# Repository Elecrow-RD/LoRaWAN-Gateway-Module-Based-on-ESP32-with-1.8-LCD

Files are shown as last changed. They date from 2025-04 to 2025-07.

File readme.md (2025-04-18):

### 1, Product picture

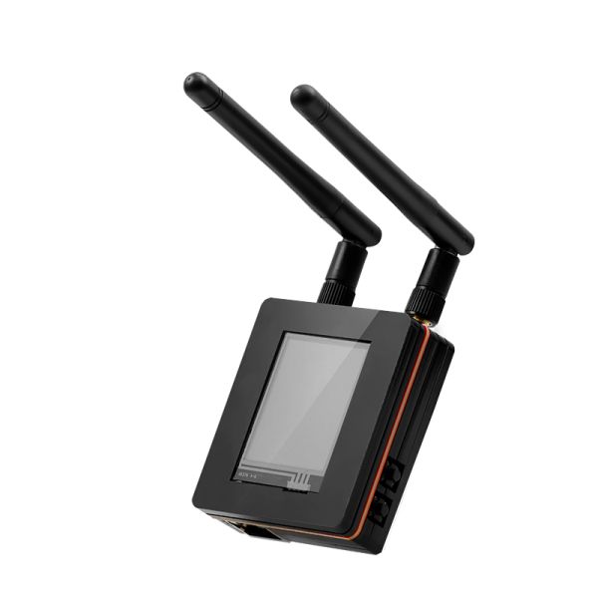
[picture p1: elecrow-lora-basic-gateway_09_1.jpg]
elecrow-lora-basic-gateway_09_1


### 2, Product version number

| | Hardware | Software | Remark |
| ---- | --- | --- | --- |
| 1 | V1.0 | V1.0 | latest |

### 3, product information

- | Main Processor Chip              | ESP32 WROOM32 with dual-core 32-bit LX6 microprocessor from Xtensa @ 240MHz |
  | -------------------------------- | ------------------------------------------------------------ |
  | LoRa RF transceiver module       | RA-01H                                                       |
  | RA-01H Supports frequency band   | 803MHZ-930MHZ                                                |
  | RA-01H Support modulation method | FSK、GFSK、MSK、LoRa                                         |
  | Channel                          | Single channel                                               |
  | Support Lorawan protocol         | Support Lorawan 1.0.3                                        |
  | WiFi Antenna                     | SMA 2.4G WiFi Antenna                                        |
  | Communication distance           | Obstructed state: up to 1 kmUnobstructed state: up to 1.8 kilometers |
  | Development environment          | Arduino/Micropython                                          |
  | Interface and function           | 1x USB-C interface,1x Ethernet Interface,1x Boot Button,1x Reset Button,2x Indicator Lights. |
  | Working input voltage            | USB DC-5V                                                    |
  | Operating Temperature            | -10°C ~ 65°C                                                 |
  | Dimensions                       | 65mm(L)x58mm(W)                                              |

### 4,Quick Start

##### Arduino IDE starts

1.Download the library files used by this product to the 'libraries' folder.

C:\Users\Documents\Arduino\libraries\



2.Open the Arduino IDE

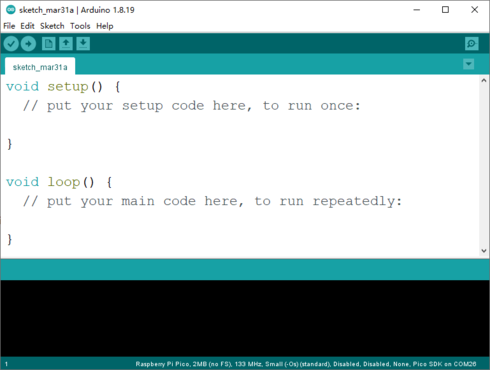
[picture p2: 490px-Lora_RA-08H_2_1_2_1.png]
490px-Lora_RA-08H_2_1_2_1


3.Open the code configuration environment and burn it

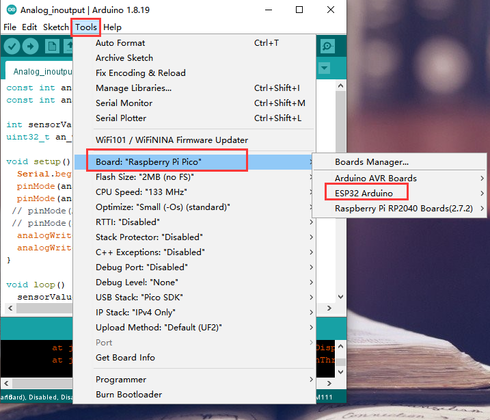
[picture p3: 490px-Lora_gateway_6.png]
490px-Lora_gateway_6


### 5,Folder structure.

|--Datasheet: Includes datasheets for components used in the project, providing detailed specifications, electrical characteristics, and pin configurations.

|--Eagle_SCH&PCB: Contains **Eagle CAD** schematic (`.sch`) and PCB layout (`.brd`) files. These are used for circuit design and PCB manufacturing.

|--example: Provides example code and projects to demonstrate how to use the hardware and libraries. These examples help users get started quickly.

|--factory_firmware: Stores pre-compiled factory firmware that can be directly flashed onto the device. This ensures the device runs the default functionality.

|--factory_sourcecode: Contains the source code for the factory firmware, allowing users to modify and rebuild the firmware as needed.

### 6,Pin definition

**IO port definition**

| GPIO0  | BOOT | GPIO1  | TXD0 | GPIO2  | RXD0 |
| --- | --- | --- | --- | --- | --- |
| GPIO3  | RXD0 | GPIO4  | LCD_DC | GPIO5  | DATA |
| GPIO6  | NC | GPIO7  | NC | GPIO8  | NC |
| GPIO9  | NC | GPIO10 | NC | GPIO11 | NC |
| GPIO12 | RA_RST | GPIO13 | RA_DIO1 | GPIO14 | RA_NSS |
| GPIO15 | XP_CS | GPIO16 | LCD_BLK | GPIO17 | RMII_CLK  |
| GPIO18 | ETH_MDIO | GPIO19 | RMII_TXD0 | GPIO20 | NC |
| GPIO21 | RMII_TX_EN  | GPIO22 | RMII_TXD1 | GPIO23 | ETH_MDC |
| GPIO24 | NC | GPIO25 | RMII_RXD0 | GPIO26 | RMII_RXD1 |
| GPIO27 | RMII_CRS_DV | GPIO28 | NC | GPIO29 | NC |
| GPIO30 | NC | GPIO31 | NC | GPIO32 | MOSI |
| GPIO33 | SCK | GPIO34 | RA_BUSY | GPIO35 | MISO |
| GPIO36 | NC | GPIO37 | NC | GPIO38 | C |
| GPIO39 | PEN | | | | |

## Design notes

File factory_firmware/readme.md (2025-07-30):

## The Wi-Fi connection password for Lora_Gateway_release_bin_v1.0 is 12345678.

## The Wi-Fi connection password for Lora_Gateway_release_bin_v2.0 is aaaabbbb.

## The firmware of zheg wifi-test can test whether your device's Wi-Fi is working properly. The Wi-Fi name is "ESP32 AP" and the password is "aaaabbbb". After connecting, check whether there is an IP address output on the serial port. If there is, it is working properly.

# How to install the factory demo firmware with flash download tool?

#### 1.Preparation:

- USB C cable
- Laptop/PC
- LoRaWAN Gateway Module Based on ESP32 with 1.8” LCD
- Flash download tool

Check whether the materials on the PCBA board are defective. Such as less material, false welding, tin and other bad phenomena.

#### 2.Flash the firmware 

##### Step1 LoRaWAN Gateway Module to the laptop/PC with USB-C cable. The power indicator will light up.

##### Step2 Open the flash download tool. 

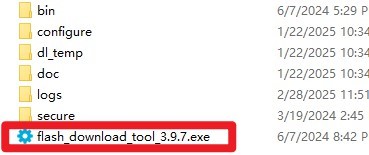
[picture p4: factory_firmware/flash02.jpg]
flash02


For the  Crowpanel Advance HMI ESP32 AI Display, the chip select ESP32:

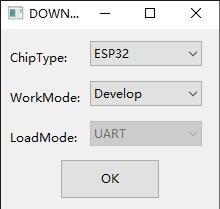
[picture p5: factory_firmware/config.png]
config


##### Step3

①Choose the firmware files;

②Enter the address: 

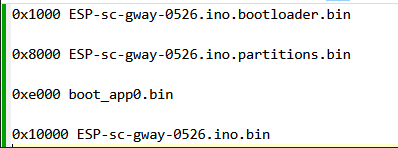
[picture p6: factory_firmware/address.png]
address


③Check the firmware files;

④Select the correct port number;

⑤Click “Start” to download

##### Step5 After the download is complete, blue FINISH will be displayed, and the progress bar at the bottom shows that it has come to an end.

download

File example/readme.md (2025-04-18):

**Arduino**: This folder contains sample programs for the Arduino platform, which is known for its ease of use and versatility in creating interactive electronic projects.

wiki:https://www.elecrow.com/wiki/lora-basic-gateway-module.html

# Library Descriptions

1. **Adafruit_BusIO**
   - A library for interfacing with various I/O devices on Adafruit platforms.

2. **Adafruit_seesaw_Library**
   - Provides support for the Adafruit Seesaw, a powerful I/O expander and controller.

3. **Adafruit_GFX-Library**
   - A graphics library that supports drawing text, images, and shapes on displays.

4. **Adafruit_ST7735-Library-master**
   - Specifically designed for ST7735-based displays, offering advanced graphical capabilities.

5. **aes**
   - Implements AES encryption and decryption algorithms for secure data handling.

6. **ArduinoJson**
   - Facilitates parsing and generating JSON data in Arduino projects.

7. **arduino.LoRa-master**
   - Supports communication using LoRa technology, ideal for long-range wireless applications.

8. **esp32-http-update**
   - Enables over-the-air updates for ESP32 devices via HTTP protocol.

9. **ESP8266_and_ESP32_Oled_Driver_for_SSD1306_display**
   - Drivers for OLED displays based on SSD1306 chips, compatible with both ESP8266 and ESP32.

10. **gBase64**
    - Encodes and decodes Base64 strings, useful for encoding binary data as ASCII characters.

11. **GUISlice-master**
    - A GUI library that simplifies creating user interfaces for embedded systems.

12. **LoRaCode**
    - Contains code snippets or examples related to LoRa communications.

13. **lv_demos-master**
    - Demonstration projects showcasing the use of LittlevGL (now LVGL), a lightweight graphics library.

14. **lvgl-master**
    - The core LittlevGL/LVGL library itself, providing rich graphical elements and widgets.

15. **Streaming**
    - Likely refers to streaming data or media; specifics would depend on implementation details not visible here.

16. **TFT_eSPI-master**
    - An optimized SPI interface driver for TFT displays, enhancing performance and functionality.

17. **TFT_Touch-master**
    - Adds touch screen capabilities to TFT displays, allowing interactive touch inputs.

18. **Time**
    - Manages time-related functions such as keeping track of system time, scheduling tasks, etc.

19. **TinyGPSPlus-1.0.2b**
    - Processes GPS data from NMEA sentences, extracting location information efficiently.

20. **WiFiManager-development**
    - Simplifies WiFi configuration by enabling users to connect to networks through a web portal.

21. **WiFiManager-master**
    - Similar to WiFiManager-development but might represent a stable release version.

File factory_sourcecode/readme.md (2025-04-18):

### 

## Key Functions in the Arduino Program

- # Function Descriptions

  ## `setup()`
  The `setup()` function is called once when the program starts. It initializes the serial communication, TFT display, touchscreen, and LVGL library. It also sets up the display driver, touchscreen driver, and initializes the UI.

  ## `loop()`
  The `loop()` function is called repeatedly and handles the main program logic. It checks for serial input to determine if the test program should run and handles the LVGL task handler to update the display.

  ## `my_disp_flush()`
  This function is a callback used by LVGL to flush the display buffer to the TFT display. It writes the pixel data to the display.

  ## `my_touchpad_read()`
  This function is a callback used by LVGL to read the touchscreen input. It retrieves the touch coordinates and updates the touch state.

  ## `touch_calibrate()`
  This function is used to calibrate the touchscreen. It prompts the user to touch specific corners of the screen and adjusts the calibration data accordingly.

  ## `label_xy()`
  This function creates label objects on the TOUCH screen to display the touch coordinates.

  ## `lv_example_bar()`
  This function creates a progress bar on the MENU screen and sets its initial value.

  ## `callback1()`
  This function is a callback used by the Ticker library to update the progress bar value and label text.

  ## `clearBufferArray()`
  This function clears the serial buffer array by setting all elements to NULL.

  ## `SD_test()`
  This function initializes the SD card and prints the directory structure to the serial monitor.

  ## `Ce_shi()`
  This function contains the test program logic. It listens for serial commands and performs various display tests such as showing colored screens, testing the touchscreen, and initializing the SD card.

  ## `lv_timer_handler()`
  This function is called to handle LVGL timer events, which are used to update the UI and handle animations.

  ## `watchdog_reboot()`
  This function reboots the system using the hardware watchdog timer.

  ## `pinMode()`
  This function sets the mode of a pin to either INPUT, OUTPUT, or INPUT_PULLUP.

  ## `digitalWrite()`
  This function writes a HIGH or LOW value to a digital pin.

  ## `analogWrite()`
  This function writes an analog value (PWM wave) to a pin.

  ## `delay()`
  This function pauses the program for the specified number of milliseconds.

  ## `Serial.begin()`
  This function initializes the serial communication with the specified baud rate.

  ## `Serial.read()`
  This function reads the next byte from the serial buffer.

  ## `Serial.println()`
  This function prints data to the serial port followed by a carriage return and newline.

  ## `tft.begin()`
  This function initializes the TFT display.

  ## `tft.setRotation()`
  This function sets the rotation of the TFT display.

  ## `tft.setTouch()`
  This function sets the touchscreen calibration data.

  ## `tft.fillScreen()`
  This function fills the entire TFT display with a specified color.

  ## `tft.getTouch()`
  This function retrieves the touch coordinates from the touchscreen.

  ## `lv_init()`
  This function initializes the LVGL library.

  ## `lv_disp_draw_buf_init()`
  This function initializes the display buffer used by LVGL.

  ## `lv_disp_drv_register()`
  This function registers the display driver with LVGL.

  ## `lv_indev_drv_register()`
  This function registers the input device driver with LVGL.

  ## `ui_init()`
  This function initializes the UI elements and screens.

  ## `lv_scr_load_anim()`
  This function loads a screen with an animation effect.

  ## `lv_obj_invalidate()`
  This function invalidates an object, causing it to be redrawn.

  ## `pinMode()`
  This function sets the mode of a pin to either INPUT, OUTPUT, or INPUT_PULLUP.

  ## `digitalWrite()`
  This function writes a HIGH or LOW value to a digital pin.

  ## `analogWrite()`
  This function writes an analog value (PWM wave) to a pin.

  ## `delay()`
  This function pauses the program for the specified number of milliseconds.

  ## `Serial.begin()`
  This function initializes the serial communication with the specified baud rate.

  ## `Serial.read()`
  This function reads the next byte from the serial buffer.

  ## `Serial.println()`
  This function prints data to the serial port followed by a carriage return and newline.

  ## `tft.begin()`
  This function initializes the TFT display.

  ## `tft.setRotation()`
  This function sets the rotation of the TFT display.

  ## `tft.setTouch()`
  This function sets the touchscreen calibration data.

  ## `tft.fillScreen()`
  This function fills the entire TFT display with a specified color.

  ## `tft.getTouch()`
  This function retrieves the touch coordinates from the touchscreen.

  ## `lv_init()`
  This function initializes the LVGL library.

  ## `lv_disp_draw_buf_init()`
  This function initializes the display buffer used by LVGL.

  ## `lv_disp_drv_register()`
  This function registers the display driver with LVGL.

  ## `lv_indev_drv_register()`
  This function registers the input device driver with LVGL.

  ## `ui_init()`
  This function initializes the UI elements and screens.

  ## `lv_scr_load_anim()`
  This function loads a screen with an animation effect.

  ## `lv_obj_invalidate()`
  This function invalidates an object, causing it to be redrawn.

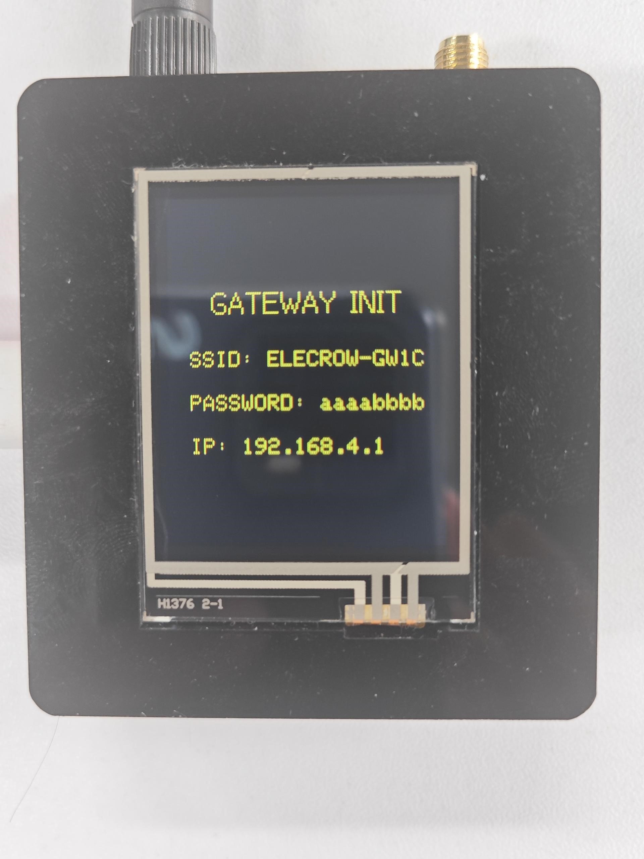
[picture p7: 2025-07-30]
factory_firmware/Lora_Gateway_release_bin_v2.0/password-aaaabbbbb.jpg

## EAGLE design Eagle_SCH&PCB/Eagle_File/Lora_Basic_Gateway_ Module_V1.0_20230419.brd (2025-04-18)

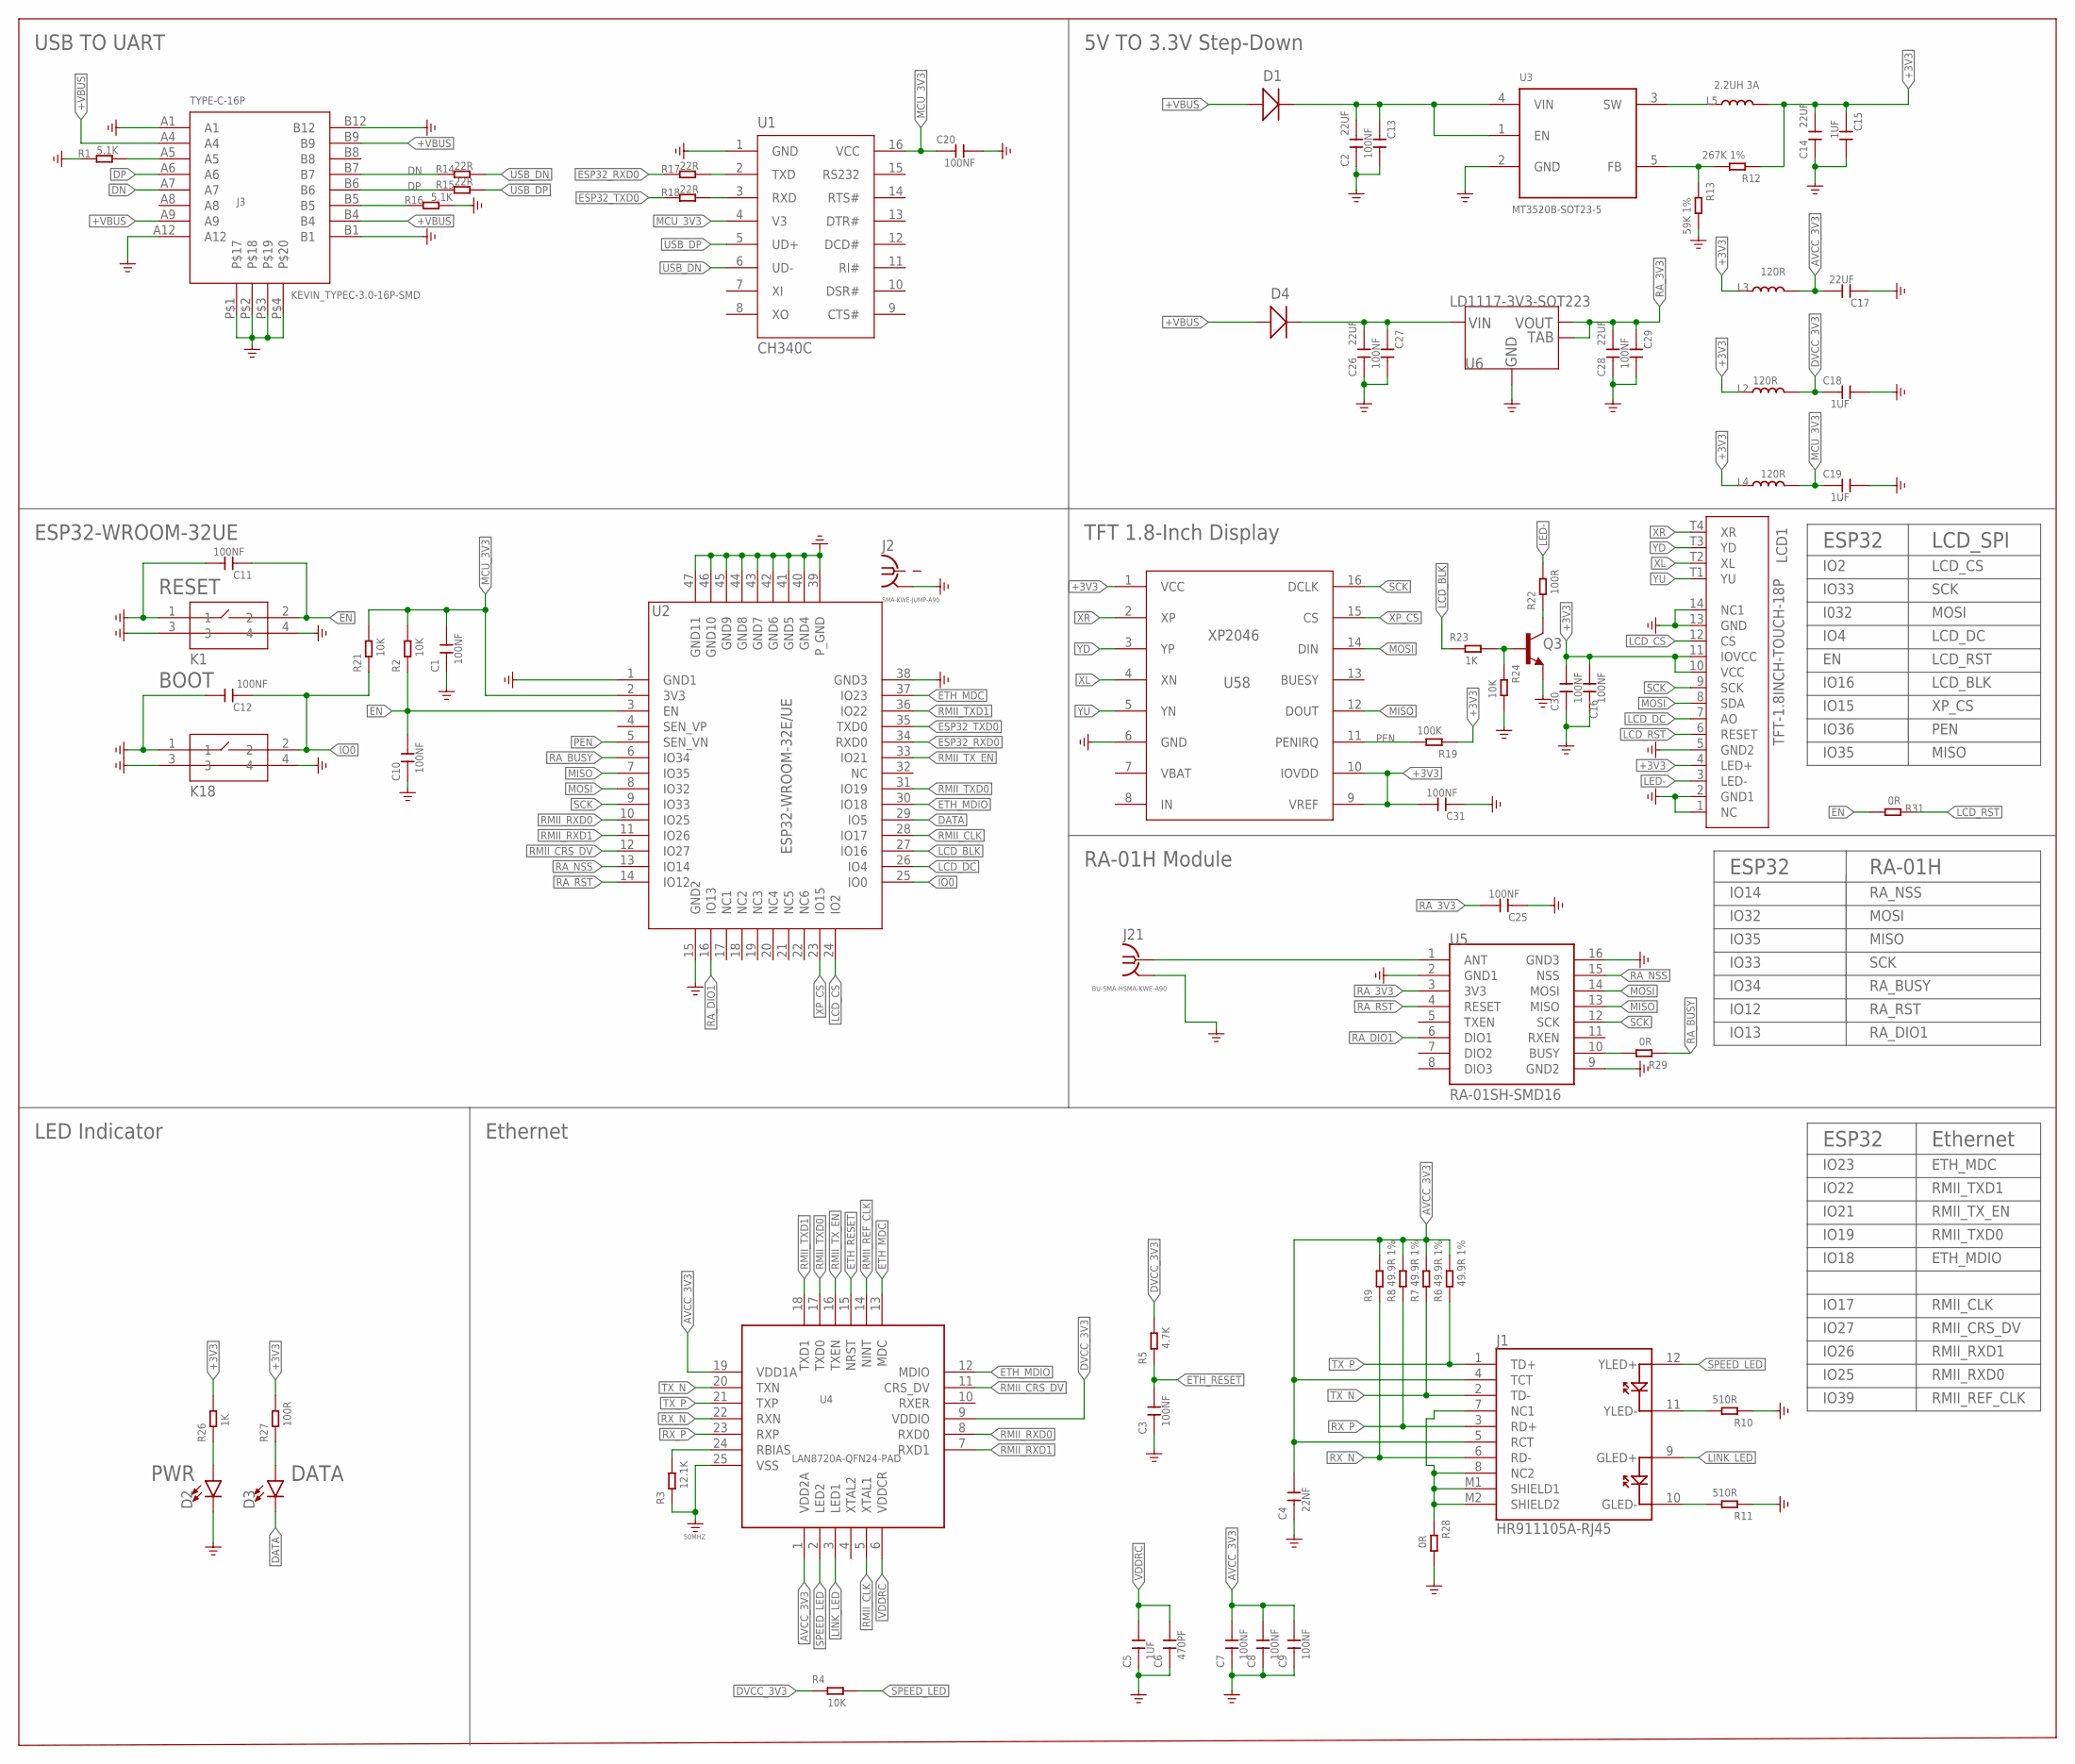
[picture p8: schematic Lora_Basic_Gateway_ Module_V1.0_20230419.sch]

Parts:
C1, C3, C7, C8, C9, C10, C11, C12, C13, C16, C20, C25, C27, C29, C30, C31: 100NF; C0603
C2, C14, C17, C26, C28: 22UF; C0805
C4: 22NF; C0603
C5, C15, C18, C19: 1UF; C0603
C6: 470PF; C0603
D1, D4: DIODEB130L-13-F; SMA
D2, D3: LED; LED-F3MM-DIP2-A90
J1: HR911105A-RJ45
J2: SMA-KWE-JUMP-A90
J3: KEVIN_TYPEC-3.0-16P-SMD; KEVIN_3.0TYPEC-SMD
J21: BU-SMA-HSMA-KWE-A90; SMA-KWE-A90
K1, K18: KEY_666MM_DIPA90; KEY_6*6*6MM_DIPA90
L2, L4: 120R; L0805
L3: 120R; L0603
L5: 2.2UH 3A; L0420
LCD1: TFT-1.8INCH-TOUCH-18P; TFT-1.8INCH-TOUCH-18P-SMD
Q3: 600mA/40V; SOT23-3
R1, R16: 5.1K; R0603
R2, R4, R21, R24: 10K; R0603
R3: 12.1K; R0603
R5: 4.7K; R0603
R6, R7, R8, R9: 49.9R 1%; R0603
R10, R11: 510R; R0603
R12: 267K 1%; R0603
R13: 59K 1%; R0603
R14, R15, R17, R18: 22R; R0603
R19: 100K; R0603
R22, R27: 100R; R0603
R23, R26: 1K; R0603
R28, R29, R31: 0R; R0603
U1: CH340C; SOP-16
U2: ESP32-WROOM-32E/UE; ESP32-WROOM-32UE
U3: MT3520B-SOT23-5; IC_SOT23-5
U4: LAN8720A-QFN24-PAD; QFN24-PAD
U5: RA-01SH-SMD16
U6: LD1117-3V3-SOT223; SOT223
U58: XP2046; XP2046-SSOP16

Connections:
+3V3: C14.2, C15.1, C16.2, C30.2, C31.2, L2.1, L3.1, L4.1, L5.2, LCD1.4 (LED+), LCD1.10 (VCC), LCD1.11 (IOVCC), R12.1, R19.1, R26.2, R27.2, U58.1 (VCC), U58.9 (VREF), U58.10 (IOVDD)
+VBUS: D1.2 (+), D4.2 (+), J3.A4, J3.A9, J3.B4, J3.B9
AVCC_3V3: C4.2, C7.2, C8.2, C9.2, C17.2, J1.4 (TCT), J1.5 (RCT), L3.2, R6.2, R7.2, R8.2, R9.2, U4.1 (VDD2A), U4.19 (VDD1A)
DATA: D3.K (C), U2.29 (IO5)
DN: J3.A7, J3.B7, R14.1
DP: J3.A6, J3.B6, R15.1
DVCC_3V3: C18.1, L2.2, R4.1, R5.2, U4.9 (VDDIO)
EN: C10.2, C11.1, K1.2, R2.1, R31.2, U2.3 (EN)
ESP32_RXD0: R17.1, U2.34 (RXD0)
ESP32_TXD0: R18.1, U2.35 (TXD0)
ETH_MDC: U2.37 (IO23), U4.13 (MDC)
ETH_MDIO: U2.30 (IO18), U4.12 (MDIO)
ETH_RESET: C3.2, R5.1, U4.15 (NRST)
GND: C1.1, C2.1, C3.1, C4.1, C5.1, C6.1, C7.1, C8.1, C9.1, C10.1, C11.2, C12.2, C13.2, C14.1, C15.2, C16.1, C17.1, C18.2, C19.2, C20.2, C25.1, C26.1, C27.2, C28.1, C29.2, C30.1, C31.1, D2.K (C), J2.2, J2.3, J2.4, J2.5, J3.A1, J3.A12, J3.B1, J3.B12, J3.P$1, J3.P$2, J3.P$3, J3.P$4, J21.2, J21.3 (2), J21.4 (2), J21.5 (2), K1.1, K1.3, K1.4, K18.1, K18.3, K18.4, LCD1.1 (NC), LCD1.2 (GND1), LCD1.5 (GND2), LCD1.13 (GND), LCD1.14 (NC1), Q3.2 (E), R1.1, R3.1, R10.1, R11.1, R13.2, R16.2, R24.2, R28.2, U1.1 (GND), U2.1 (GND1), U2.15 (GND2), U2.38 (GND3), U2.39 (P_GND), U2.40 (GND4), U2.41 (GND5), U2.42 (GND6), U2.43 (GND7), U2.44 (GND8), U2.45 (GND9), U2.46 (GND10), U2.47 (GND11), U3.2 (GND), U4.25 (VSS), U5.2 (GND1), U5.9 (GND2), U5.16 (GND3), U6.1 (GND), U58.6 (GND)
IO0: C12.1, K18.2, R21.1, U2.25 (IO0)
LCD_BLK: R23.1, U2.27 (IO16)
LCD_CS: LCD1.12 (CS), U2.24 (IO2)
LCD_DC: LCD1.7 (AO), U2.26 (IO4)
LCD_RST: LCD1.6 (RESET), R31.1
LED-: LCD1.3 (LED-), R22.2
LINK_LED: J1.9 (GLED+), U4.3 (LED1)
MCU_3V3: C1.2, C19.1, C20.1, L4.2, R2.2, R21.2, U1.4 (V3), U1.16 (VCC), U2.2 (3V3)
MISO: U2.7 (IO35), U5.13 (MISO), U58.12 (DOUT)
MOSI: LCD1.8 (SDA), U2.8 (IO32), U5.14 (MOSI), U58.14 (DIN)
unnamed: Q3.3 (C), R22.1
unnamed: D2.A, R26.1
unnamed: D3.A, R27.1
unnamed: C26.2, C27.1, D4.1 (-), U6.3 (VIN)
unnamed: R29.2, U5.10 (BUSY)
unnamed: J1.7 (NC1), J1.8 (NC2), J1.M1 (SHIELD1), J1.M2 (SHIELD2), R28.1
unnamed: Q3.1 (B), R23.2, R24.1
unnamed: J1.10 (GLED-), R11.2
unnamed: J21.1, U5.1 (ANT)
unnamed: J1.11 (YLED-), R10.2
unnamed: C2.2, C13.1, D1.1 (-), U3.1 (EN), U3.4 (VIN)
unnamed: R12.2, R13.1, U3.5 (FB)
unnamed: R3.2, U4.24 (RBIAS)
unnamed: L5.1, U3.3 (SW)
unnamed: J3.B5, R16.1
unnamed: J3.A5, R1.2
unnamed: R17.2, U1.2 (TXD)
unnamed: R18.2, U1.3 (RXD)
PEN: R19.2, U2.5 (SEN_VN), U58.11 (PENIRQ)
RA_3V3: C25.2, C28.2, C29.1, U5.3 (3V3), U6.2 (VOUT), U6.4 (TAB)
RA_BUSY: R29.1, U2.6 (IO34)
RA_DIO1: U2.16 (IO13), U5.6 (DIO1)
RA_NSS: U2.13 (IO14), U5.15 (NSS)
RA_RST: U2.14 (IO12), U5.4 (RESET)
RMII_CLK: U2.28 (IO17), U4.5 (XTAL1)
RMII_CRS_DV: U2.12 (IO27), U4.11 (CRS_DV)
RMII_REF_CLK: U4.14 (NINT)
RMII_RXD0: U2.10 (IO25), U4.8 (RXD0)
RMII_RXD1: U2.11 (IO26), U4.7 (RXD1)
RMII_TXD0: U2.31 (IO19), U4.17 (TXD0)
RMII_TXD1: U2.36 (IO22), U4.18 (TXD1)
RMII_TX_EN: U2.33 (IO21), U4.16 (TXEN)
RX_N: J1.6 (RD-), R9.1, U4.22 (RXN)
RX_P: J1.3 (RD+), R8.1, U4.23 (RXP)
SCK: LCD1.9 (SCK), U2.9 (IO33), U5.12 (SCK), U58.16 (DCLK)
SPEED_LED: J1.12 (YLED+), R4.2, U4.2 (LED2)
TX_N: J1.2 (TD-), R7.1, U4.20 (TXN)
TX_P: J1.1 (TD+), R6.1, U4.21 (TXP)
USB_DN: R14.2, U1.6 (UD-)
USB_DP: R15.2, U1.5 (UD+)
VDDRC: C5.2, C6.2, U4.6 (VDDCR)
XL: LCD1.T2 (XL), U58.4 (XN)
XP_CS: U2.23 (IO15), U58.15 (CS)
XR: LCD1.T4 (XR), U58.2 (XP)
YD: LCD1.T3 (YD), U58.3 (YP)
YU: LCD1.T1 (YU), U58.5 (YN)

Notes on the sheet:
ESP32
Ethernet
ETH_MDC
RMII_TXD1
RMII_TX_EN
RMII_TXD0
ETH_MDIO
RMII_CLK
RMII_CRS_DV
RMII_RXD1
RMII_RXD0
IO23
IO22
IO21
IO19
IO18
IO17
IO27
IO26
IO25
LCD_SPI
LCD_CS
SCK
MOSI
LCD_DC
LCD_RST
LCD_BLK
IO2
IO33
I032
IO4
IO16
RA-01H
RA_NSS
MISO
RA_BUSY
RA_RST
IO14
IO32
IO35

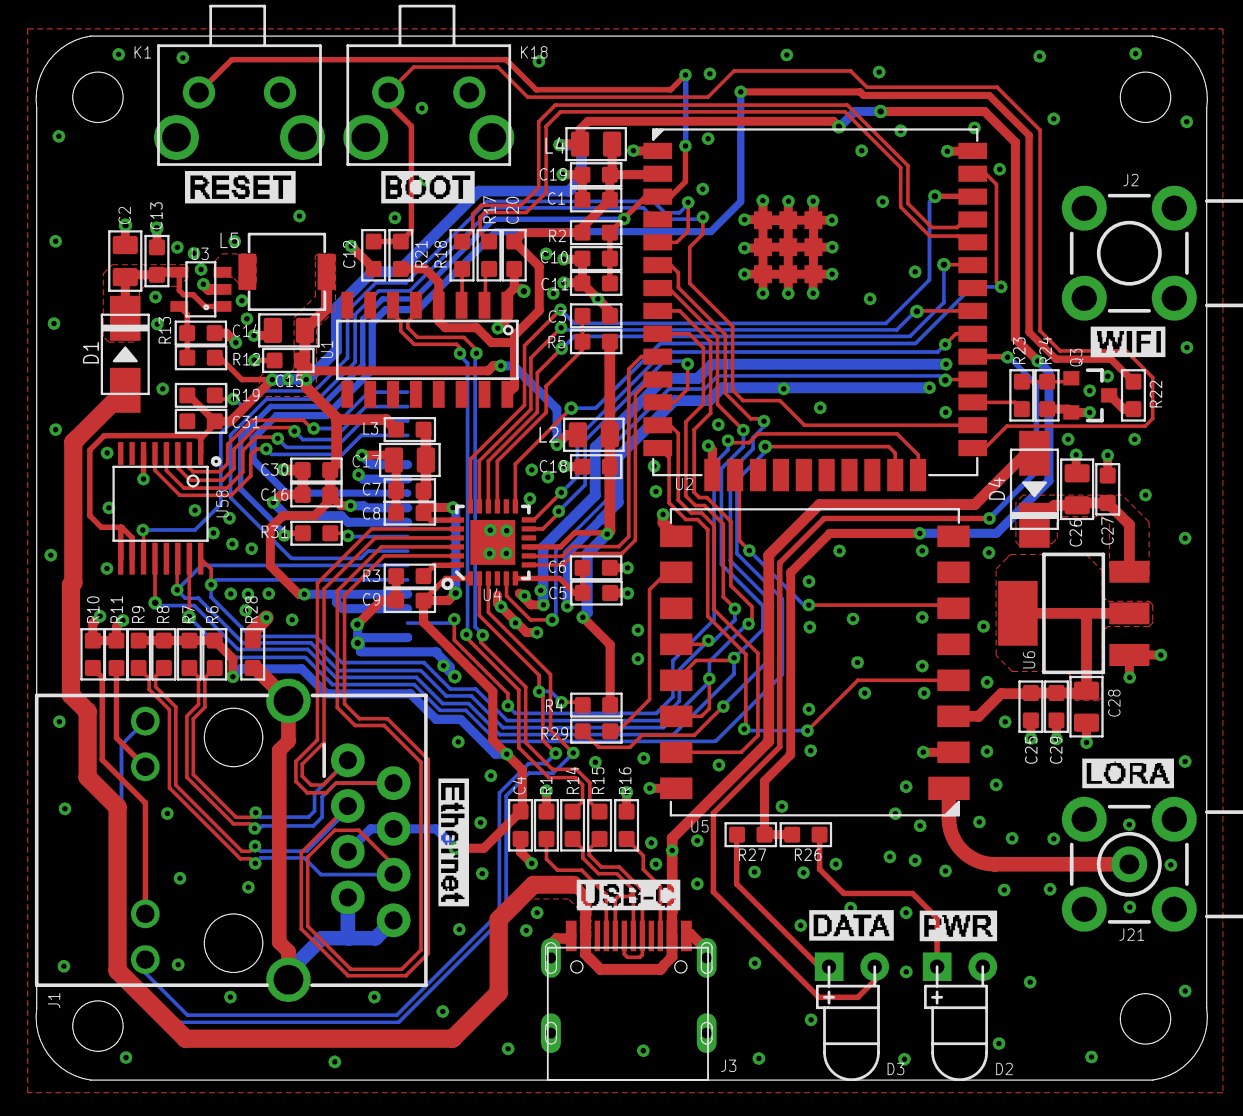
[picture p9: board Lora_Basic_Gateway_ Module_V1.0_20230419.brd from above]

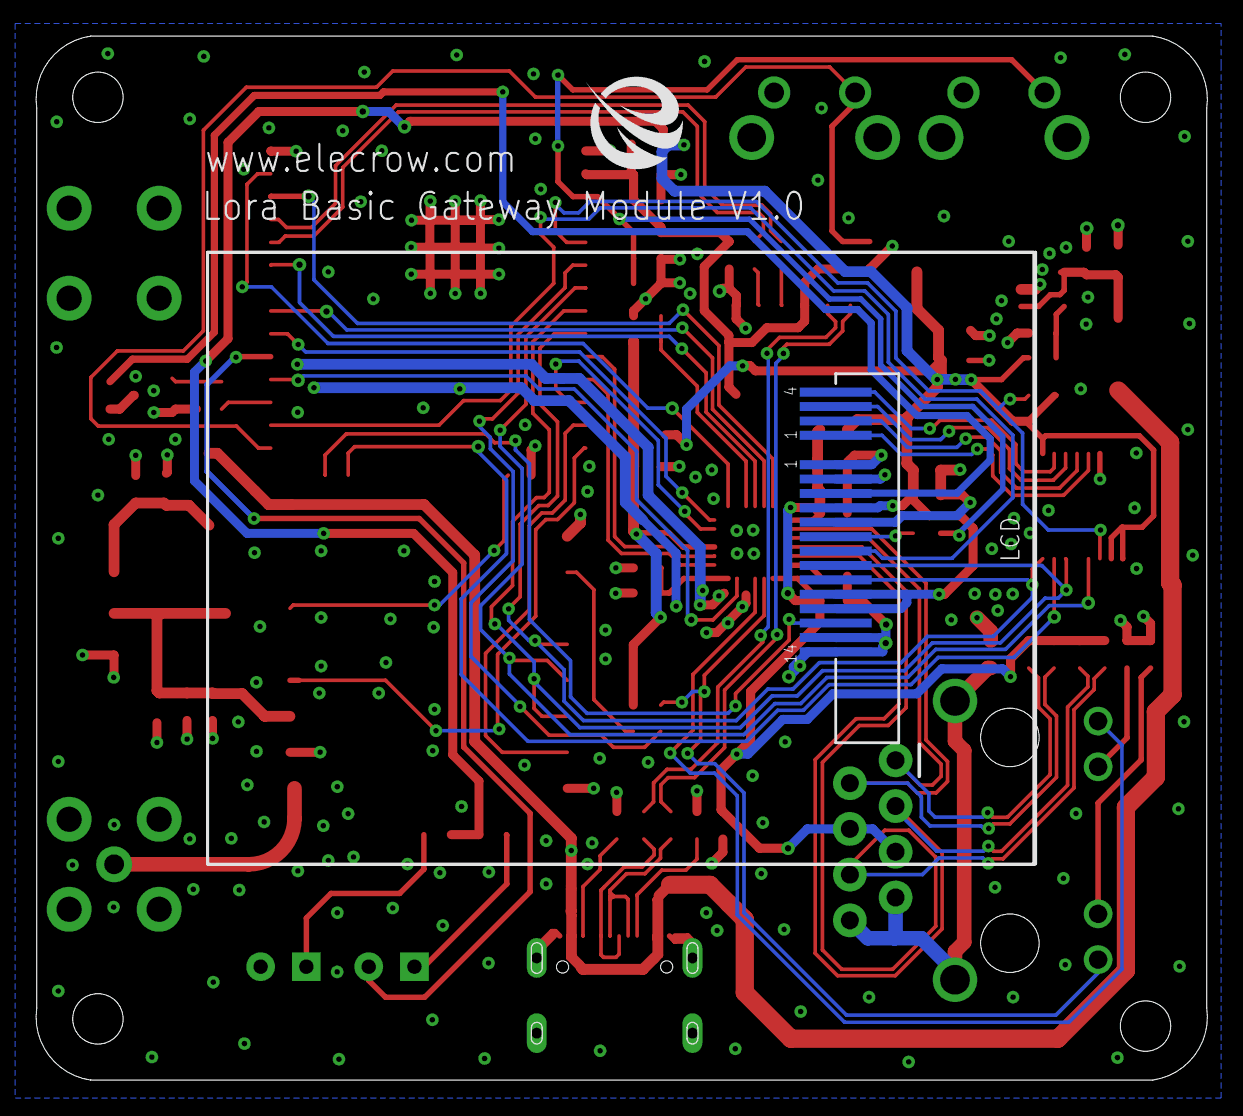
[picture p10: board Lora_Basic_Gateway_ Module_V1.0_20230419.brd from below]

Board: 2 copper layers, 65.1 x 58.0 mm, 79 parts (2 on the bottom side), 69 nets.

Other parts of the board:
U$160: ELECROW-NEW

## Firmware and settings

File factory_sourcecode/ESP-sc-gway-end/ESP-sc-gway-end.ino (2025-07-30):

// 1-channel LoRa Gateway for ESP8266 and ESP32     20230408
// Copyright (c) 2016-2020 free
//
// Based on work done by Thomas Telkamp for Raspberry PI 1-ch gateway and many others.
//
// All rights reserved. This program and the accompanying materials
// are made available under the terms of the MIT License
// which accompanies this distribution, and is available at
// https://opensource.org/licenses/mit-license.php
//
// NO WARRANTY OF ANY KIND IS PROVIDED
//
// The protocols and specifications used for this 1ch gateway:
// 1. LoRA Specification version V1.0 and V1.1 for Gateway-Node communication
//
// 2. Semtech Basic communication protocol between Lora gateway and server version 3.0.0
//	https://github.com/Lora-net/packet_forwarder/blob/master/PROTOCOL.TXT
//
// Notes:
// - Once call hostbyname() to get IP for services, after that only use IP
//	 addresses (too many gethost name makes the ESP unstable)
// - Only call yield() in main stream (not for background NTP sync).
//
// ----------------------------------------------------------------------------------------
#define ESP32_ARCH 1  //定义ESP32 SPI

#if defined (ARDUINO_ARCH_ESP32) || defined(ESP32)
#	define ESP32_ARCH 1
#	ifndef _PIN_OUT
#		define _PIN_OUT 4									// For ESP32 pin-out 4 is default
#	endif
#elif defined(ARDUINO_ARCH_ESP8266)
//
#else
#	error "Architecture unknown and not supported"
#endif


// The followion file contains most of the definitions
// used in other files. It should be the first file.
#include "configGway.h"										// contains the configuration data of GWay
#include "configNode.h"										// Contains the personal data of Wifi etc.

#include <Esp.h>											// ESP8266 specific IDE functions
#include <string.h>
#include <stdio.h>
#include <sys/types.h>
#include <unistd.h>
#include <fcntl.h>
#include <cstdlib>
//#include <time.h>
#include <sys/time.h>
#include <cstring>
#include <string>											// C++ specific string functions

#include <SPI.h>											// For the RFM95 bus
#include <TimeLib.h>										// http://playground.arduino.cc/code/time
#include <ArduinoJson.h>
#include <FS.h>												// ESP8266 Specific
#include <WiFiUdp.h>
#include <pins_arduino.h>
#include <gBase64.h>										// https://github.com/adamvr/arduino-base64 (changed the name)

// Local include files
#include "loraModem.h"
#include "loraFiles.h"
#include "oLED.h"

extern "C" {
#	include "lwip/err.h"
#	include "lwip/dns.h"
}

#if (_GATEWAYNODE==1) || (_LOCALSERVER==1)
#	include "AES-128_V10.h"
#endif

// ----------- Specific ESP32 stuff --------------
#if defined(ESP32_ARCH)
#	include <WiFi.h>
#	include <ESPmDNS.h>
#	include <SPIFFS.h>
#	include <WiFiManager.h>								// Standard lib for ESP WiFi config through an AP

#	define ESP_getChipId()   ((uint32_t)ESP.getEfuseMac())

//#	if _SERVER==1
//#		include <WebServer.h>								// Standard Webserver for ESP32
//#		include <Streaming.h>          						// http://arduiniana.org/libraries/streaming/
//WebServer server(_SERVERPORT);
//#	endif //_SERVER


#include <WiFi.h>
//#include <DNSServer.h>
#include <WebServer.h>
#include <Preferences.h>


// ----------- Specific ESP8266 stuff --------------
#elif defined(ARDUINO_ARCH_ESP8266)
extern "C" {
#		include "user_interface.h"
#		include "c_types.h"
}
#	include <ESP8266WiFi.h>									// Which is specific for ESP8266
#	include <ESP8266mDNS.h>
#	include <WiFiManager.h>									// Library for ESP WiFi config through an AP

#	define ESP_getChipId()   (ESP.getChipId())

#	if _SERVER==1
#		include <ESP8266WebServer.h>
#		include <Streaming.h>          						// http://arduiniana.org/libraries/streaming/
ESP8266WebServer server(_SERVERPORT);				// Standard IDE lib
#	endif //_SERVER

#	if _OTA==1
#		include <ESP8266httpUpdate.h>
#		include <ArduinoOTA.h>
#	endif //_OTA


#else
#	error "Architecture not supported"

#endif //ESP_ARCH

#include <DNSServer.h>										// Local DNSserver


// ----------- Declaration of variables --------------

bool led_show = false;
bool show_flag = true;
String Rx_last_time = "";
String Tx_last_time = "";
int Rx_cont = 0;
int Tx_cont = 0;
String sys_time = "";
uint8_t debug = 1;											// Debug level! 0 is no msgs, 1 normal, 2 extensive
uint8_t pdebug = P_MAIN ;									// Initially only MAIN and GUI

#if _GATEWAYNODE==1
#	if _GPS==1
#		include <TinyGPS++.h>
TinyGPSPlus gps;
HardwareSerial sGps(1);
#	endif //_GPS
#endif //_GATEWAYNODE

using namespace std;
byte 		currentMode = 0x81;
bool		sx1272 = true;									// Actually we use sx1276/RFM95

#define GATEWAY_REST_PIN 0
#define GATEWAY_RXTX_PIN 5
// ----------------------------------------------------------------------------
//
// Configure these values only if necessary!
//
// ----------------------------------------------------------------------------

// Set spreading factor (SF7 - SF12)
sf_t sf;							// Initial value of SF

// Set location, description and other configuration parameters
// Defined in ESP-sc_gway.h
//
float lat			= _LAT;									// Configuration specific info...
float lon			= _LON;
int   alt			= _ALT;
char platform[24]	= _PLATFORM; 							// platform definition
char email[40]		= _EMAIL;    							// used for contact email
char description[64] = _DESCRIPTION;							// used for free form description

// JSON definitions
StaticJsonDocument<312> jsonBuffer;							// Use of arduinoJson version 6!

// define servers

IPAddress ntpServer;										  // IP address of NTP_TIMESERVER
IPAddress ttnServer;										  // IP Address of thethingsnetwork server
IPAddress thingServer;										// Only if we use a second (backup) server

#include <ETH.h> //引用以使用ETH
#define ETH_PHY_ADDR    0
#define ETH_PHY_POWER  -1
#define ETH_PHY_MDC    23
#define ETH_PHY_MDIO   18
#define ETH_PHY_TYPE   ETH_PHY_LAN8720
#define ETH_CLK_MODE   ETH_CLOCK_GPIO17_OUT

WiFiUDP Udp;

time_t startTime = 0;										  // The time in seconds since 1970 that the server started.
uint32_t eventTime = 0;										// Timing of _event to change value (or not).
uint32_t sendTime = 0;										// Time that the last message transmitted
uint32_t doneTime = 0;										// Time to expire when CDDONE takes too long
uint32_t statTime = 0;										// last time we sent a stat message to server
uint32_t pullTime = 0;										// last time we sent a pull_data request to server
uint32_t rstTime  = 0;										// When to reset the timer
uint32_t fileTime = 0;										// Write the configuration to file

#define TX_BUFF_SIZE  1024								// Upstream buffer to send to MQTT
#define RX_BUFF_SIZE  1024								// Downstream received from MQTT
#define STATUS_SIZE	  512									// Should(!) be enough based on the static text .. was 1024

#if _SERVER==1
uint32_t wwwtime = 0;
#endif
#if NTP_INTR==0
uint32_t ntptimer = 0;
#endif
#if _GATEWAYNODE==1
uint16_t frameCount = 0;									// We write this to SPIFF file
#endif
#ifdef _PROFILER
uint32_t endTmst = 0;
#endif

// Init the indexes of the data we display on the webpage
// We use this for circular buffers
uint16_t iMoni = 0;
uint16_t iSeen = 0;
uint16_t iSens = 0;

// volatile bool inSPI This initial value of mutex is to be free,
// which means that its value is 1 (!)
//
int16_t mutexSPI = 1;

// ----------------------------------------------------------------------------
// FORWARD DECLARATIONS
// These forward declarations are done since other .ino fils are linked by the
// compiler/linker AFTER the main ESP-sc-gway.ino file.
// And espcecially when calling functions with ICACHE_RAM_ATTR the complier
// does not want this.
// Solution can also be to specify less STRICT compile options in Makefile
// ----------------------------------------------------------------------------

void ICACHE_RAM_ATTR Interrupt_0();
void ICACHE_RAM_ATTR Interrupt_1();

int sendPacket(uint8_t *buf, uint8_t length);							// _txRx.ino forward

void printIP(IPAddress ipa, const char sep, String & response);			// _wwwServer.ino
void setupWWW();														// _wwwServer.ino forward

void mPrint(String txt);												// _utils.ino
int getNtpTime(time_t *t);												// _utils.ino
int mStat(uint8_t intr, String & response);								// _utils.ino
void SerialStat(uint8_t intr);											// _utils.ino
void printHexDigit(uint8_t digit, String & response);					// _utils.ino
int inDecodes(char * id);												// _utils.ino
static void stringTime(time_t t, String & response);					// _utils.ino

int initMonitor(struct moniLine *monitor);								// _loraFiles.ino
void initConfig(struct espGwayConfig *c);								// _loraFiles.ino
int writeSeen(const char *fn, struct nodeSeen *listSeen);				// _loraFiles.ino
int readGwayCfg(const char *fn, struct espGwayConfig *c);				// _loraFiles.ino

void setupOta(char *hostname);											// _otaServer.ino

void initLoraModem();													// _loraModem.ino
void rxLoraModem();														// _loraModem.ino
void writeRegister(uint8_t addr, uint8_t value);						// _loraModem.ino
void cadScanner();														// _loraModem.ino
void startReceiver();													// _loraModem.ino

void stateMachine();													// _stateMachine.ino

bool connectUdp();														// _udpSemtech.ino
int readUdp(int packetSize);											// _udpSemtech.ino
int sendUdp(IPAddress server, int port, uint8_t *msg, uint16_t length);		// _udpSemtech.ino
void sendstat();														// _udpSemtech.ino
void pullData();														// _udpSemtech.ino

#if _MUTEX==1
void ICACHE_FLASH_ATTR CreateMutux(int *mutex);
bool ICACHE_FLASH_ATTR GetMutex(int *mutex);
void ICACHE_FLASH_ATTR ReleaseMutex(int *mutex);
#endif


void init_ST7735();
void ST7735_Clear();
void ST7735_SHOW_TEST(int x, int y, int w, int h, int text_x, int text_y, String str, int str_font, int str_size);   //显示字符
void ROLL_Text(int x, int y, int w, int h, int text_x, int text_y, String str, int str_font, int str_size);
bool ST7735_GET_TOUCH();

Preferences prefs;
const char* AP_NAME = "ELECROW-GW1C";//Web配网模式下的AP-wifi名字
const char* AP_PASSWORD = "aaaabbbb";//Web配网模式下的AP-wifi密码

//暂时存储Gateway配置信息
char sta_gatewayMode[32] = {0};
char sta_ssid[64] = {0};
char sta_password[64] = {0};
char sta_gatewayid[64] = {0};
char sta_serverAddr[64] = {0};
char sta_serverPort[64] = {0};
char sta_region[32] = {0};
char sta_getway_channel[32] = {0};
char sta_getway_sf[32] = {0};
char sta_getway_utc[32] = {0};
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
void loop ()
{

  int cont_rest = 0;
  // 检测按键是否按下，当按键按下时将返回低电平
  if (digitalRead(GATEWAY_REST_PIN) == LOW) {
    delay(50);
    // 按键按下 计时
    while(digitalRead(GATEWAY_REST_PIN) == LOW)
    {
      delay(100);
      cont_rest++;
      Serial.println("rest cont = " + String(cont_rest));
      if(cont_rest == 30)
      {        
        prefs.begin("gatewayConfig",false);//为false才能删除键值
        Serial.println(prefs.freeEntries());//查询清除前的剩余空间
        
        prefs.remove("netMode"); 
        prefs.remove("wifiid"); 
        prefs.remove("wifipass"); 
        prefs.remove("gatewayid"); 
        prefs.remove("serverAddr"); 
        prefs.remove("serverPort"); 
        prefs.remove("region"); 
        prefs.remove("getway_channel"); 
        prefs.remove("getway_sf"); 
        prefs.clear();

        ST7735_Clear();
        delay(500);
        Serial.println(prefs.freeEntries());//查询清除后的剩余空间
        prefs.end();
    
        Serial.println("remove config --> ESP32 restart ");
        ESP.restart(); //重启ESP32
      }
    }
    
  } 

  int packetSize;
  uint32_t nowSeconds = now();

  gateway_server.handleClient();

   if(mode_getwag == "wifi" || mode_getwag == "net") 
  {

      ST7735_GET_TOUCH();
    
      // So if we are connected
      // Receive UDP PUSH_ACK messages from server. (*2, par. 3.3)
      // This is important since the TTN broker will return confirmation
      // messages on UDP for every message sent by the gateway. So we have to consume them.
      // As we do not know when the server will respond, we test in every loop.
      while ( (packetSize = Udp.parsePacket()) > 0) {
    #		if _MONITOR>=1
        if ((debug >= 3) && (pdebug & P_TX)) {
          mPrint("loop:: readUdp available");
        }
    #		endif //_MONITOR
    
        // DOWNSTREAM
        // Packet may be PKT_PUSH_ACK (0x01), PKT_PULL_ACK (0x03) or PKT_PULL_RESP (0x04)
        // This command is found in byte 4 (buffer[3])
    
        if (readUdp(packetSize) < 0) {
    #			if _MONITOR>=1
          if (debug >= 0)
            mPrint("Dwn readUdp ERROR, returning < 0");
    #			endif //_MONITOR
          break;
        }
        // Now we know we succesfully received message from host
        // If return value is 0, we received a NTP message,
        // otherwise a UDP message with other TTN content, all ACKs are 4 bytes long
        else {
          //_event=1;									// Could be done double if more messages received
          //mPrint("Dwn udp received="+String(micros())+", packetSize="+String(packetSize));
        }
      }
    
      yield();
    
      // check for event value, which means that an interrupt has arrived.
      // In this case we handle the interrupt ( e.g. message received)
      // in userspace in loop().
      //
      stateMachine();											// do the state machine
    
      // After a quiet period, make sure we reinit the modem and state machine.
      // The interval is in seconds (about 15 seconds) as this re-init
      // is a heavy operation.
      // So it will kick in if there are not many messages for the gateway.
      // Note: Be careful that it does not happen too often in normal operation.
      //
      if ( ((nowSeconds - statr[0].time) > _MSG_INTERVAL) &&
           (msgTime <= statr[0].time) )
      {
    #		if _MONITOR>=1
        if ((debug >= 2) && (pdebug & P_MAIN)) {
          String response = "";
          response += "REINIT:: ";
          response += String( _MSG_INTERVAL );
          response += (" ");
          mStat(0, response);
          mPrint(response);
        }
    #		endif //_MONITOR
    
        yield();											// Allow buffer operations to finish
    
        if ((gwayConfig.cad) || (gwayConfig.hop)) {
          _state = S_SCAN;
          sf = SF7;
          cadScanner();
        }
        else {
          _state = S_RX;
          rxLoraModem();
        }
        writeRegister(REG_IRQ_FLAGS_MASK, (uint8_t) 0x00);
        writeRegister(REG_IRQ_FLAGS, (uint8_t) 0xFF);		// Reset all interrupt flags
        msgTime = nowSeconds;
      }
    
      // If event is set, we know that we have a (soft) interrupt.
      // After all necessary web/OTA services are scanned, we will
      // reloop here for timing purposes.
      // Do as less yield() as possible.
      if (_event == 1) {
        return;
      }
      else yield();
       
      // stat PUSH_DATA message (*2, par. 4)
      //
      if ((nowSeconds - statTime) >= _STAT_INTERVAL) {		// Wake up every xx seconds
        yield();											// on 26/12/2017
        sendstat();											// Show the status message and send to server
    #		if _MONITOR>=1
        if ((debug >= 2) && (pdebug & P_MAIN)) {
          mPrint("Send Pushdata sendstat");
        }
    #		endif //_MONITOR
    
        // If the gateway behaves like a node, we do from time to time
        // send a node message to the backend server.
        // The Gateway node message has nothing to do with the STAT_INTERVAL
        // message but we schedule it in the same frequency.
        //
    #		if _GATEWAYNODE==1
        if (gwayConfig.isNode) {
          // Give way to internal some Admin if necessary
          yield();
    
          // If the 1ch gateway is a sensor itself, send the sensor values
          // could be battery but also other status info or sensor info
    
          if (sensorPacket() < 0) {
    #				if _MONITOR>=1
            if ((debug >= 1) || (pdebug & P_MAIN)) {
              mPrint("sensorPacket: Error");
            }
    #				endif //_MONITOR
          }
        }
    #		endif//_GATEWAYNODE
        statTime = nowSeconds;
      }
    
    
      // send PULL_DATA message (*2, par. 4)
      //
      // This message will also restart the server which taken approx. 3 ms.
      nowSeconds = now();
      if ((nowSeconds - pullTime) >= _PULL_INTERVAL) {		// Wake up every xx seconds
    
        yield();
        pullData();											// Send PULL_DATA message to server
        //startReceiver();
        pullTime = nowSeconds;
    
    #		if _MONITOR>=1
        if ((debug >= 2) && (pdebug & P_RX)) {
          String response = "UP ESP-sc-gway:: PKT_PULL_DATA message sent: micr=";
          printInt(micros(), response);
          mPrint(response);
        }
    #		endif //_MONITOR
      }
    
    
      // send RESET_DATA message (*2, par. 4)
      //
      // This message will also restart the server which taken approx. 3 ms.
      nowSeconds = now();
      if ((nowSeconds - rstTime) >= _RST_INTERVAL) {			// Wake up every xx seconds
    
        yield();
        startReceiver();
        rstTime = nowSeconds;
    
    #		if _MONITOR>=1
        if ((debug >= 2) && (pdebug & P_MAIN)) {
          String response = "UP ESP-sc-gway:: RST_DATA message sent: micr=";
          printInt(micros(), response);
          mPrint(response);
        }
    #		endif //_MONITOR
      }
    
    
      // If we do our own NTP handling (advisable)
      // We do not use the timer interrupt but use the timing
      // of the loop() itself which is better for SPI
//    #	if NTP_INTR==0
//      // Set the time in a manual way. Do not use setSyncProvider
//      //  as this function may collide with SPI and other interrupts
//      // Note: It can be that we do not receive a time this loop (no worries)
//      yield();
//      if (nowSeconds - ntptimer >= _NTP_INTERVAL) {
//        yield();
//        time_t newTime;
//        if (getNtpTime(&newTime) <= 0) {
//    #				if _MONITOR>=1
//          if (debug >= 2) {
//            mPrint("loop:: WARNING Time not set (yet). Time=" + String(newTime) );
//          }
//    #				endif //_MONITOR
//        }
//        else {
//          setTime(newTime);
//          if (year(now()) != 1970) {						// Do not when year(now())=="1970"
//            ntptimer = nowSeconds;						// beacause of "FORMAT"
//          }
//        }
//      }
//    #	endif//NTP_INTR
    
//    #	if _MAXSEEN>=1
//      if ((nowSeconds - fileTime) >= _FILE_INTERVAL) {
//        writeSeen(_SEENFILE, listSeen);
//        fileTime = nowSeconds;
//      }
//    #	endif //_MAXSEEN
    
  }
  else
  {
     #if _MONITOR>=1
        Serial.println("Config Network ....");
        delay(1000);
    #endif //_MONITOR
  }

}//loop

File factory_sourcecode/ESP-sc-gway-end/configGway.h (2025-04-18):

// 1-channel LoRa Gateway for ESP32 and ESP8266
// Copyright (c) 2016-2020 

#define VERSION "V.6.2.5.EU868"

//
// Based on work done by Thomas Telkamp for Raspberry PI 1ch gateway and many others.
//
// All rights reserved. This program and the accompanying materials
// are made available under the terms of the MIT License
// which accompanies this distribution, and is available at
// https://opensource.org/licenses/mit-license.php
//
// NO WARRANTY OF ANY KIND IS PROVIDED
//
// This file contains a number of compile-time settings that can be set on (=1) or off (=0)
// The disadvantage of compile time is minor compared to the memory gain of not having
// too much code compiled and loaded on your ESP device.
//
// NOTE: 
// If version is for ESP32 Heltec board, compile with ESP32 setting and board 
// "ESP32 Dev Module" or "Heltec WiFi Lora 32"
// 
// For ESP8266 Wemos: compile with "Wemos R1 D1" and choose
// the right _PIN_OUT below. Selecting Oled while that is not connected does not 
// really matter (so you can leave that in).
//
// The source has been optimized for PlatformIO usage. That means some variables
// can be defined in the .platformio.ini file. Please look at the example file to see 
// how to set these #defines
//
// ========================================================================================


// Define whether we should do a formatting of SPIFFS when starting the gateway
// This is usually a good idea if the webserver is interrupted halfway a writing
// operation. Also to be used when software is upgraded
// Normally, value 0 is a good default and should not be changed.
#if !defined _SPIFFS_FORMAT
#	define _SPIFFS_FORMAT 0
#endif


// Allows configuration through WifiManager AP setup. Must be 0 or 1	
#if !defined _WIFIMANAGER				
#	define _WIFIMANAGER 0
#endif


// Debug message will be put on Serial is this one is set.
// If set to 0, no printing to USB devices is done.
// Set to 1 it will print all user level messages (with correct debug set)
// If set to 2 it will also print interrupt messages (not recommended)
#if !defined _DUSB
#	define _DUSB 1
#endif


// Define the monitor screen. When it is greater than 0 then logging is displayed in
// the special screen at the GUI.
// If _DUSB is also set to 1 then most messages will also be copied to USB devices.
#if !defined _MONITOR
#	define _MONITOR 1
#endif


// Gather statistics on sensor and Wifi status
// 0= No statistics
// 1= Keep track of messages statistics, number determined by _MAXSTAT
// 2= Option 1 + Keep track of messages received PER each SF (default)
// 3= See Option 2, but with extra channel info (Not used when Hopping is not selected)
#if !defined _STATISTICS
#	define _STATISTICS 3
#endif

// Define the frequency band the gateway will listen on. Valid options are
// EU863_870	Europe 
// US902_928	North America
// AU925_928	Australia
// CN470_510	China
// IN865_867	India
// CN779-787	(Not Used!)
// EU433		Europe
// AS923		(Not Used)
// You can find the definitions in "loraModem.h" and frequencies in
// See https://www.thethingsnetwork.org/docs/lorawan/frequency-plans.html
//#define EU863_870 1
 

// Define the CLASS mode of the gateway
// A: Baseline Class
// B: Beacon/Battery Class
// C: Continuous Listen Class
#define _CLASS "A"


// Define whether to use the old Semtech gateway API, which is still supported by TTN,
// but is more lightweight than the new TTN tcp based protocol.
// NOTE: Only one of the two should be defined! TTN Router project has stopped
//
#define _UDPROUTER 1
//#define _TTNROUTER 1


// The spreading factor is the most important parameter to set for a single channel
// gateway. It specifies the speed/datarate in which the gateway and node communicate.
// As the name says, in principle the single channel gateway listens to one channel/frequency
// and to one spreading factor only.
// This parameters contains the default value of SF, the actual version can be set with
// the webserver and it will be stored in SPIFF
// NOTE: The frequency is set in the loraModem.h file and is default 868.100000 MHz.
//#define _SPREADING SF7


// Channel Activity Detection
// This function will scan for valid LoRa headers and determine the Spreading 
// factor accordingly. If set to 1 we will use this function which means the 
// 1-channel gateway will become even more versatile. If set to 0 we will use the
// continuous listen mode.
// Using this function means that we HAVE to use more dio pins on the RFM95/sx1276
// device and also connect enable dio1 to detect this state. 
#define _CAD 0


// CRCCHECK
// Defines whether we should check on the CRC of RXDONE messages (see stateMachine.ino)
// This should prevent us from getting a lot os stranges messgages of unknown nodes.
// Note: DIO3 must be connected for this to work (Heltec and later Wemos gateways). 
#define _CRCCHECK 1
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

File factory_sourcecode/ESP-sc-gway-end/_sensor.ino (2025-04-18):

// sensor.ino; 1-channel LoRa Gateway for ESP8266 and ESP32
// Copyright (c) 2016-2020 
//
// All rights reserved. This program and the accompanying materials
// are made available under the terms of the MIT License
// which accompanies this distribution, and is available at
// https://opensource.org/licenses/mit-license.php
//
// NO WARRANTY OF ANY KIND IS PROVIDED
//
// This file contains code for using the single channel gateway also as a sensor node. 
// Please specify the DevAddr and the AppSKey below (and on your LoRa backend).
// Also you will have to choose what sensors to forward to your application.
//
// Note: disable sensors not used in configGway.h
//	- The GPS is included on TTGO T-Beam ESP32 boards by default.
//	- The battery sensor works by connecting the VCC pin to A0 analog port
// ============================================================================
	
#if _GATEWAYNODE==1

#include "LoRaCode.h"

unsigned char DevAddr[4]  = _DEVADDR ;				// see configGway.h


// Only used by GPS sensor code
#if _GPS==1
// ----------------------------------------------------------------------------
// Smartdelay is a function to delay processing but in the loop get info 
// from the GPS device
// ----------------------------------------------------------------------------
void smartDelay(uint32_t ms)                
{
	uint32_t start = millis();
	do
	{
		while (sGps.available()) {
			gps.encode(sGps.read());
		}
		yield();									// MMM Maybe  enable to fill buffer
	} while (millis() - start < ms);
}
#endif //_GPS





// ----------------------------------------------------------------------------
// LoRaSensors() is a function that puts sensor values in the MACPayload and 
// sends these values up to the server. For the server it is impossible to know 
// whther or not the message comes from a LoRa node or from the gateway.
//
// The example code below adds a battery value in lCode (encoding protocol) but
// of-course you can add any byte string you wish
//
// Parameters: 
//	- buf: contains the buffer to put the sensor values in (max==xx);
// Returns:
//	- The amount of sensor characters put in the buffer
//
// NOTE: The code in LoRaSensors() is provided as an example only.
//	The amount of sensor values as well as their message layout may differ
//	for each implementation.
//	Also, the message format used by this gateway is LoraCode, a message format
//	developed by me for sensor values. Each value is uniquely coded with an
//	id and a value, and the total message contains its length (less than 64 bytes)
//	and a parity value in byte[0] bit 7.
// ----------------------------------------------------------------------------
int LoRaSensors(uint8_t *buf) {

#	if defined(_LCODE)
#		if defined(_RAW) 
#		error "Only define ONE encoding in configNode.h, _LOCDE or _RAW"
#		endif

		String response="";
		uint8_t tchars = 1;
		buf[0] = 0x86;								// 134; User code <lCode + len==3 + Parity
		
#		if _MONITOR>=1
		if ((debug>=1) && (pdebug & P_MAIN)) {
			response += "LoRaSensors:: ";
		}
#		endif //_MONITOR

		// GPS sensor is the second server we check for
#		if _GPS==1
			smartDelay(10);							// Use GPS to return fast!
			if ((millis() > 5000) && (gps.charsProcessed() < 10)) {
#				if _MONITOR>=1
					mPrint("ERROR: No GPS data received: check wiring");
#				endif //_MONITOR
				return(0);
			}
			// Assuming we have a value, put it in the buf
			// The layout of this message is specific to the user,
			// so adapt as needed.

			// Use lcode to code messages to server
#			if _MONITOR>=1
			if ((debug>=1) && (pdebug & P_MAIN)) {
				response += " Gps lcode:: lat="+String(gps.location.lat())+", lng="+String(gps.location.lng())+", alt="+String(gps.altitude.feet()/3.2808)+", sats="+String(gps.satellites.value());
			}
#			endif //_MONITOR
			tchars += lcode.eGpsL(gps.location.lat(), gps.location.lng(), gps.altitude.value(), gps.satellites.value(), buf + tchars);
#		endif //_GPS

#		if _BATTERY==1
#			if defined(ARDUINO_ARCH_ESP8266) || defined(ESP32)
				// For ESP there is no standard battery library
				// What we do is to measure GPIO35 pin which has a 100K voltage divider
				pinMode(35, INPUT);
				float volts=3.3 * analogRead(35) / 4095 * 2;	// T_Beam connects to GPIO35
#			else
				// For ESP8266 no sensor defined
				float volts=0;
#			endif // ARDUINO_ARCH_ESP8266 || ESP32
#			if _MONITOR>=1
			if ((debug>=1) && (pdebug & P_MAIN)){
				response += ", Battery V="+String(volts);
			}
#			endif //_MONITOR

			tchars += lcode.eBattery(volts, buf + tchars);
#		endif //_BATTERY


		// If all sensor data is encoded, we encode the buffer
		lcode.eMsg(buf, tchars);								// Fill byte 0 with bytecount and Parity
		
#		if _MONITOR>=1
			mPrint(response);
#		endif //_MONITOR

// Second encoding option is RAW format. 
//
// We do not use the lcode format but write all the values to the output
// buffer and we need to get them in sequence out off the buffer.
#	elif defined(_RAW)
		uint8_t tchars = 0;

		// GPS sensor is the second server we check for
#		if _GPS==1
			smartDelay(10);
			if (millis() > 5000 && gps.charsProcessed() < 10) {
#				if _MONITOR>=1
					mPrint("ERROR: No GPS data received: check wiring");
#				endif //_MONITOR
				return(0);
			}
			// Raw coding of LoRa messages to server so add the GPS data raw to the string
#			if _MONITOR>=1
			if ((debug>=1) && (pdebug & P_MAIN)){
				mPrint("Gps raw:: lat="+String(gps.location.lat())+", lng="+String(gps.location.lng())+", alt="+String(gps.altitude.feet()/3.2808)+", sats="+String(gps.satellites.value()) );
				//mPrint("Gps raw:: sizeof double="+String(sizeof(double)) );
			}
#			endif //_MONITOR
			// Length of lat and lng is double
			double lat = gps.location.lat();
			double lng = gps.location.lng();
			double alt = gps.altitude.feet() / 3.2808;
			memcpy((buf+tchars), &lat, sizeof(double)); tchars += sizeof(double);
			memcpy((buf+tchars), &lng, sizeof(double)); tchars += sizeof(double);
			memcpy((buf+tchars), &alt, sizeof(double)); tchars += sizeof(double);
#		endif //_GPS

#		if _BATTERY==1
#			if defined(ARDUINO_ARCH_ESP8266) || defined(ESP32)
				// For ESP there is no standard battery library
				// What we do is to measure GPIO35 pin which has a 100K voltage divider
				pinMode(35, INPUT);
				float volts=3.3 * analogRead(35) / 4095 * 2;	// T_Beam connects to GPIO35
#			else
				// For ESP8266 no sensor defined
				float volts=0;
#			endif // ARDUINO_ARCH_ESP8266 || ESP32
			memcpy((buf+tchars), &volts, sizeof(float)); tchars += sizeof(float);
			
#			if _MONITOR>=1
			if ((debug>=1) && (pdebug & P_MAIN)){
				mPrint("Battery raw="+String(volts));
			}
#			endif //_MONITOR
#		endif //_BATTERY


// If neither _LCODE or _RAW is defined this is an error
#	else
#		error "Please define an encoding format as in configNode.h"
#	endif
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

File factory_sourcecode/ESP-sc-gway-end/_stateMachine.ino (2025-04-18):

// 1-channel LoRa Gateway for ESP8266 and ESP32
// Copyright (c) 2016-2020 version for ESP8266
//
// 	based on work done by Thomas Telkamp for Raspberry PI 1ch gateway
//	and many others.
//
// All rights reserved. This program and the accompanying materials
// are made available under the terms of the MIT License
// which accompanies this distribution, and is available at
// https://opensource.org/licenses/mit-license.php
//
// NO WARRANTY OF ANY KIND IS PROVIDED
//
// This file contains the state machine code enabling to receive
// and transmit packages/messages.
// ============================================================================================
//


// --------------------------------------------------------------------------------------------
// stateMachine handler of the state machine.
// We use ONE state machine for all kind of interrupts. This assures that we take
// the correct action upon receiving an interrupt.
//
// _event is the software interrupt: If set this function is executed from loop(),
// the function should itself take care of setting or resetting the variable.
//
// STATE MACHINE
// The program uses the following state machine (in _state), all states
// are done in interrupt routine, only the follow-up of S-RXDONE is done
// in the main loop() program. This is because otherwise the interrupt processing
// would take too long to finish
//
// So _state has one of the following state values:
//
// S-INIT=0, 	The commands in this state are executed only once
//	- Goto S_SCAN
//
// S-SCAN, 		CadScanner() part
//	- Upon CDDECT (int1) goto S_RX, 
//	- upon CDDONE (int0) goto S_CAD, walk through all SF until CDDETD
//	- Else stay in SCAN state
//
// S-CAD, 		
//	- Upon CDDECT (int1) goto S_RX,
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

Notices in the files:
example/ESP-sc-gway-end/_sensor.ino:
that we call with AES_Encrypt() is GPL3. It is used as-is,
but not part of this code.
